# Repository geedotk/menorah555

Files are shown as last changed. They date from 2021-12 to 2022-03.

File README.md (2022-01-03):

# Menorah555

Menorah555 is an LED menorah that uses flickering LEDs to simulate the candles.
The shamash (helper candle) is removed and used to "light" the other candles.

## Circuit:
The menorah is built around LEDs that look like standard 5-mm LEDs (T-1 3/4), but
they actually have a chip inside that applies PWM to the LED to simulate a 
flickering flame. This means that no special driver circuitry is needed to create
that effect. Thus, the circuit has no microcontroller in it.

The shamash "candle" has a single flickering LED driven with a super cap. The shamash
board is a daughter board that can be unplugged, and the super cap will allow the
LED to keep lit for a while. A current limiter circuit keeps the inrush current down
so that charging the super cap does not cause the power supply to trip the current limit.

The "candle" lighting circuits are built around 555 timers. This could have been done
with fewer parts in a number of ways, but the 555 was selected to silence the
pundits that say, "it could have been done with a 555!" The 555 on each candle is used as
a set-reset flip-flop. Another 555 timer is configured to provide a power-on reset to
ensure that all LEDs (except for the shamash) are unlit when power is turned on. Triggering
of the 555 to turn on the LED is done with a reed switch. The shamash PCB has a magnet
mounted on it to trigger the reed switch and "light" the candle.

## PCB
Schematic capture and PCB layout were done in [KiCad](https://www.kicad.org/) 6.0.0.
There is no problem fitting everything on the PCB because the size is dictated more
by the aesthetics than the component size. In fact, the electrolytic capacitors selected
are MUCH larger than necessary because they are part of the suggestion of a candle shape.

## Base
The base of the menorah was designed in [FreeCAD](https://www.freecadweb.org/) 0.19 and
was designed to be made of acrylic or similar plastic and bent to the proper final
shape. It's not always easy to be consistent in heat-bending acrylic, so it may be better
to drill the mounting holes after bending. Otherwise, the base may not sit flat on a table.

## Flame Diffusors
The flame diffusors were designed in FreeCAD and were meant to be FDM printed in transparent
filament. The layer lines and in-fill will help to diffuse the light.

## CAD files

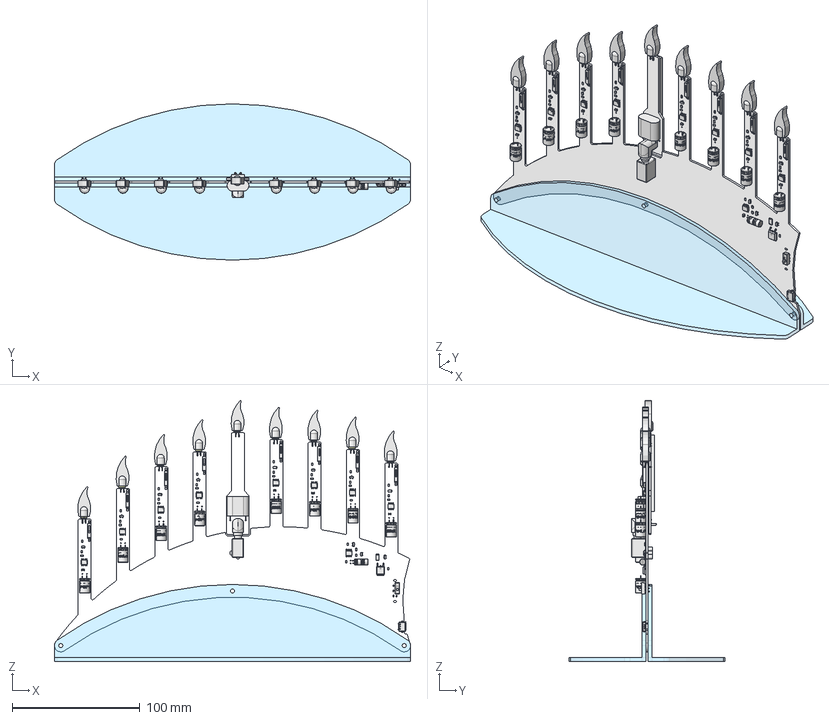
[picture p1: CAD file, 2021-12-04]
FreeCAD/menorah555_3d_model/menorah555_assembly.FCStd
278.6 x 122.2 x 204.3 mm
flame_diffuser001
base front
base rear
flame_diffusers_main

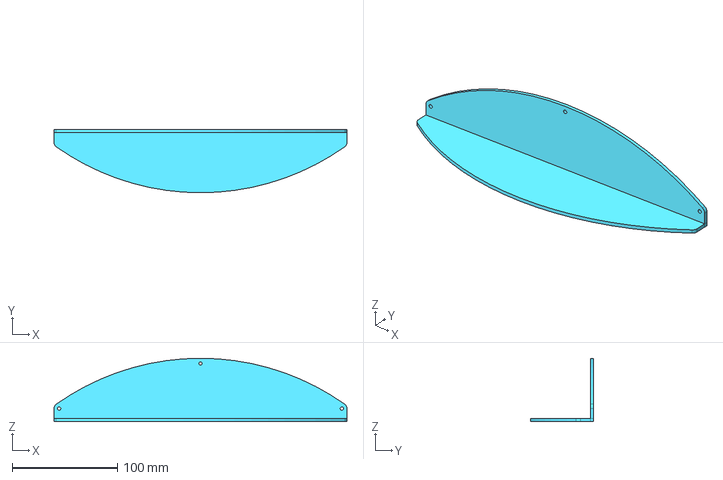
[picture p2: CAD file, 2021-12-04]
FreeCAD/base/menorah_base.step
278.6 x 60.3 x 60.3 mm

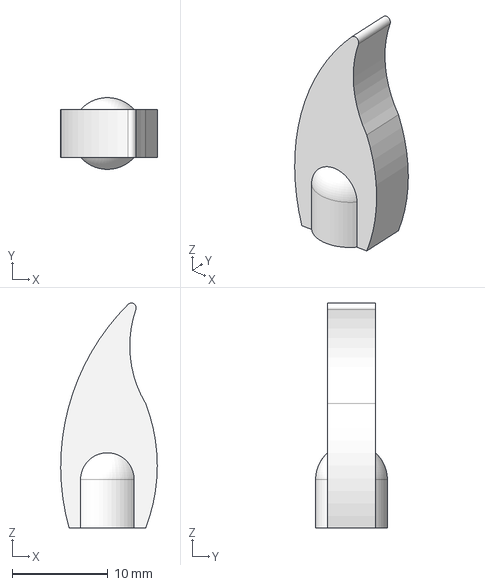
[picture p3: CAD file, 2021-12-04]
FreeCAD/flame_diffuser/flame_diffuser.step
10.1 x 7.50 x 23.5 mm

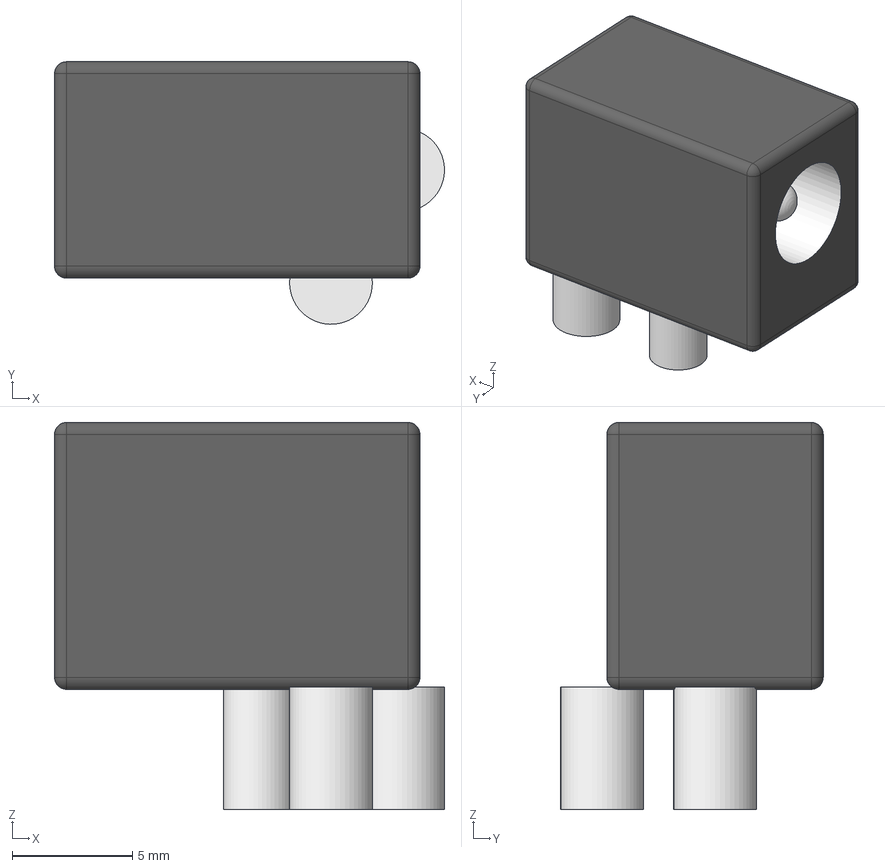
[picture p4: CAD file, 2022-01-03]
KiCad/menorah555_main/project_libraries/project_3dmodels/CON-SOCJ-2155.stp
16.2 x 10.9 x 16.1 mm

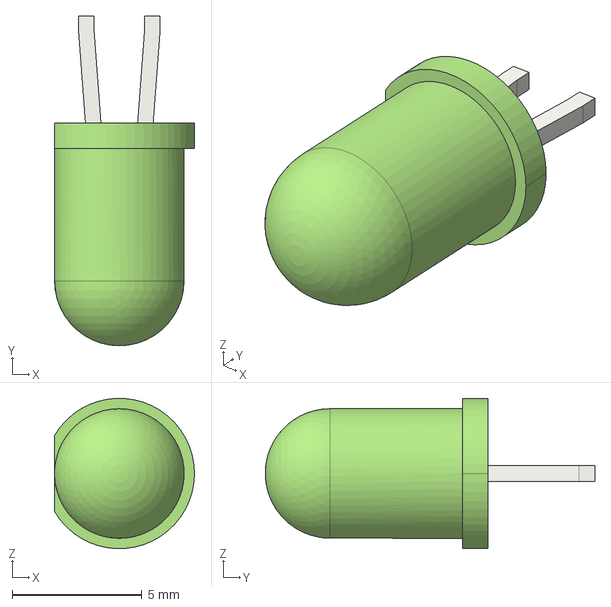
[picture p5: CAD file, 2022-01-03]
KiCad/menorah555_shamash/project_libraries/project_3dmodels/LED_D5.00mm_SMT_Horizontal_O3.81mm.step
5.40 x 12.7 x 5.79 mm

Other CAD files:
FreeCAD/base/menorah_base.FCStd
FreeCAD/flame_diffuser/flame_diffuser.FCStd
FreeCAD/flame_diffuser/flame_diffuser.stl

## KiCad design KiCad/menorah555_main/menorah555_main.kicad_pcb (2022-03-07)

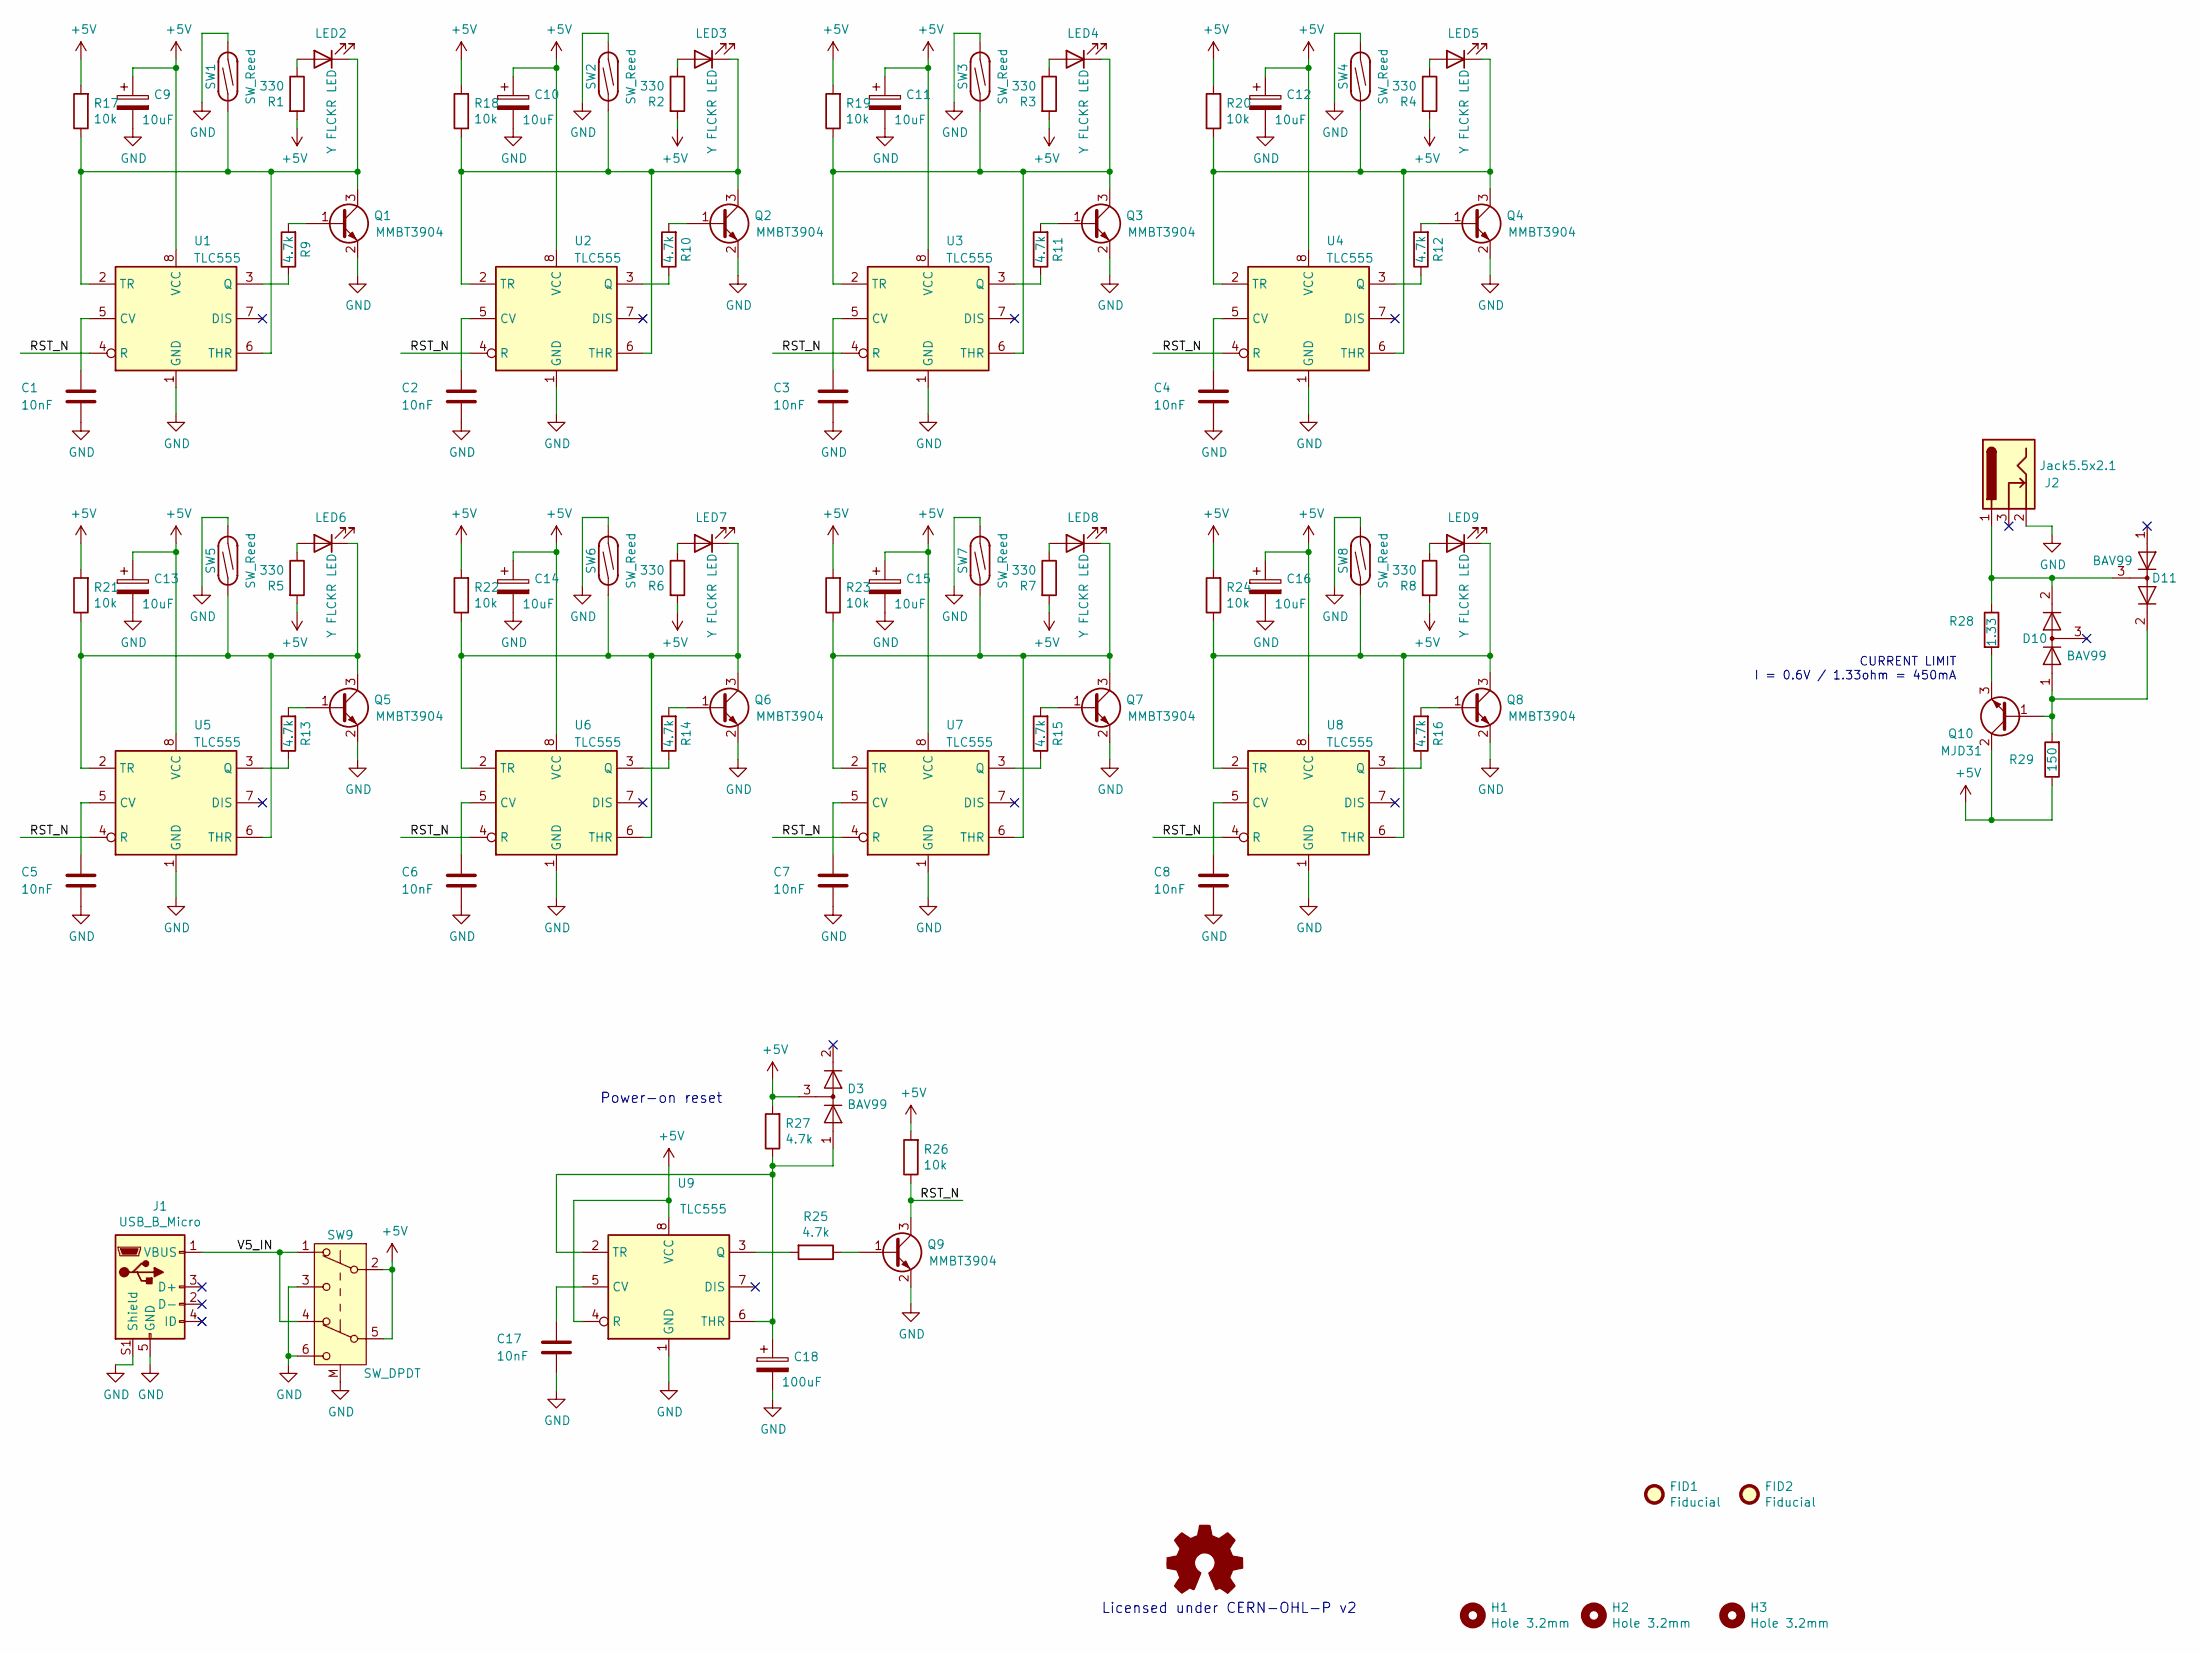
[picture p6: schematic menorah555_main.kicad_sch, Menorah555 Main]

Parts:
C1, C2, C3, C4, C5, C6, C7, C8, C17: 10nF; C_0805_2012Metric
C9, C10, C11, C12, C13, C14, C15, C16: 10uF; CP_Radial_Horizontal_D8.0mm_L12.0mm_P3.50mm
C18: 100uF; CP_Radial_Horizontal_D5.0mm_H11.0mm_P2.00mm
D3, D10, D11: BAV99; SOT-23
FID1, FID2: Fiducial; Fiducial_1mm_Mask2mm
H1, H2, H3: Hole 3.2mm; MountingHole_3.2mm_M3
J1: USB_B_Micro; AMPHENOL_10118194-0001LF
J2: Jack5.5x2.1; Gravitech_CONSOCJ2155_2.1mm_5.5mm_Barrel_Jack_Z2.35
LED2, LED3, LED4, LED5, LED6, LED7, LED8, LED9: Y FLCKR LED; LED_D5.0mm_Horizontal_SMT_O3.81mm
LOGO2: Logo_Open_Hardware_Small; OSHW-Logo2_9.8x8mm_SilkScreen
Q1, Q2, Q3, Q4, Q5, Q6, Q7, Q8, Q9: MMBT3904; SOT-23
Q10: MJD31; TO-252-2
R1, R2, R3, R4, R5, R6, R7, R8: 330; R_0805_2012Metric
R9, R10, R11, R12, R13, R14, R15, R16, R25, R27: 4.7k; R_0805_2012Metric
R17, R18, R19, R20, R21, R22, R23, R24, R26: 10k; R_0805_2012Metric
R28: 1.33; R_2010_5025Metric
R29: 150; R_0805_2012Metric
SW1, SW2, SW3, SW4, SW5, SW6, SW7, SW8: SW_Reed; SW_SPST_REED_59170-1-S-00-D
SW9: SW_DPDT; SW_Nidec_MFS201N-9-Z_DPDT_Straight
U1, U2, U3, U4, U5, U6, U7, U8, U9: TLC555; SOIC-8_3.9x4.9mm_P1.27mm

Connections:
+5V: C9.1, C10.1, C11.1, C12.1, C13.1, C14.1, C15.1, C16.1, D3.3 (K), Q10.2 (C), R1.2, R2.2, R3.2, R4.2, R5.2, R6.2, R7.2, R8.2, R17.2, R18.2, R19.2, R20.2, R21.2, R22.2, R23.2, R24.2, R26.2, R27.2, R29.1, SW9.2 (B), SW9.5 (B), U1.8 (VCC), U2.8 (VCC), U3.8 (VCC), U4.8 (VCC), U5.8 (VCC), U6.8 (VCC), U7.8 (VCC), U8.8 (VCC), U9.4 (R), U9.8 (VCC)
/RST_N: Q9.3 (C), R26.1, U1.4 (R), U2.4 (R), U3.4 (R), U4.4 (R), U5.4 (R), U6.4 (R), U7.4 (R), U8.4 (R)
/V5_IN: J1.1 (VBUS), SW9.1 (A), SW9.4 (A)
GND: C1.2, C2.2, C3.2, C4.2, C5.2, C6.2, C7.2, C8.2, C9.2, C10.2, C11.2, C12.2, C13.2, C14.2, C15.2, C16.2, C17.2, C18.2, J1.5 (GND), J1.S1 (Shield), J1.S2 (Shield), J1.S3 (Shield), J1.S4 (Shield), J1.S5 (Shield), J1.S6 (Shield), J2.2, Q1.2 (E), Q2.2 (E), Q3.2 (E), Q4.2 (E), Q5.2 (E), Q6.2 (E), Q7.2 (E), Q8.2 (E), Q9.2 (E), SW1.2, SW2.2, SW3.2, SW4.2, SW5.2, SW6.2, SW7.2, SW8.2, SW9.3 (C), SW9.6 (C), SW9.M, U1.1 (GND), U2.1 (GND), U3.1 (GND), U4.1 (GND), U5.1 (GND), U6.1 (GND), U7.1 (GND), U8.1 (GND), U9.1 (GND)
unnamed: C1.1, U1.5 (CV)
unnamed: C2.1, U2.5 (CV)
unnamed: C3.1, U3.5 (CV)
unnamed: C4.1, U4.5 (CV)
unnamed: C5.1, U5.5 (CV)
unnamed: C6.1, U6.5 (CV)
unnamed: C7.1, U7.5 (CV)
unnamed: C8.1, U8.5 (CV)
unnamed: C17.1, U9.5 (CV)
unnamed: C18.1, D3.1 (K), R27.1, U9.2 (TR), U9.6 (THR)
unnamed: D10.1 (K), D11.2 (A), Q10.1 (B), R29.2
unnamed: D10.2 (A), D11.3 (K), J2.1, R28.1
unnamed: LED2.1 (K), Q1.3 (C), R17.1, SW1.1, U1.2 (TR), U1.6 (THR)
unnamed: LED2.2 (A), R1.1
unnamed: LED3.1 (K), Q2.3 (C), R18.1, SW2.1, U2.2 (TR), U2.6 (THR)
unnamed: LED3.2 (A), R2.1
unnamed: LED4.1 (K), Q3.3 (C), R19.1, SW3.1, U3.2 (TR), U3.6 (THR)
unnamed: LED4.2 (A), R3.1
unnamed: LED5.1 (K), Q4.3 (C), R20.1, SW4.1, U4.2 (TR), U4.6 (THR)
unnamed: LED5.2 (A), R4.1
unnamed: LED6.1 (K), Q5.3 (C), R21.1, SW5.1, U5.2 (TR), U5.6 (THR)
unnamed: LED6.2 (A), R5.1
unnamed: LED7.1 (K), Q6.3 (C), R22.1, SW6.1, U6.2 (TR), U6.6 (THR)
unnamed: LED7.2 (A), R6.1
unnamed: LED8.1 (K), Q7.3 (C), R23.1, SW7.1, U7.2 (TR), U7.6 (THR)
unnamed: LED8.2 (A), R7.1
unnamed: LED9.1 (K), Q8.3 (C), R24.1, SW8.1, U8.2 (TR), U8.6 (THR)
unnamed: LED9.2 (A), R8.1
unnamed: Q1.1 (B), R9.2
unnamed: Q2.1 (B), R10.2
unnamed: Q3.1 (B), R11.2
unnamed: Q4.1 (B), R12.2
unnamed: Q5.1 (B), R13.2
unnamed: Q6.1 (B), R14.2
unnamed: Q7.1 (B), R15.2
unnamed: Q8.1 (B), R16.2
unnamed: Q9.1 (B), R25.1
unnamed: Q10.3 (E), R28.2
unnamed: R9.1, U1.3 (Q)
unnamed: R10.1, U2.3 (Q)
unnamed: R11.1, U3.3 (Q)
unnamed: R12.1, U4.3 (Q)
unnamed: R13.1, U5.3 (Q)
unnamed: R14.1, U6.3 (Q)
unnamed: R15.1, U7.3 (Q)
unnamed: R16.1, U8.3 (Q)
unnamed: R25.2, U9.3 (Q)

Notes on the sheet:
Power-on reset
CURRENT LIMIT I = 0.6V / 1.33ohm = 450mA
Licensed under CERN-OHL-P v2

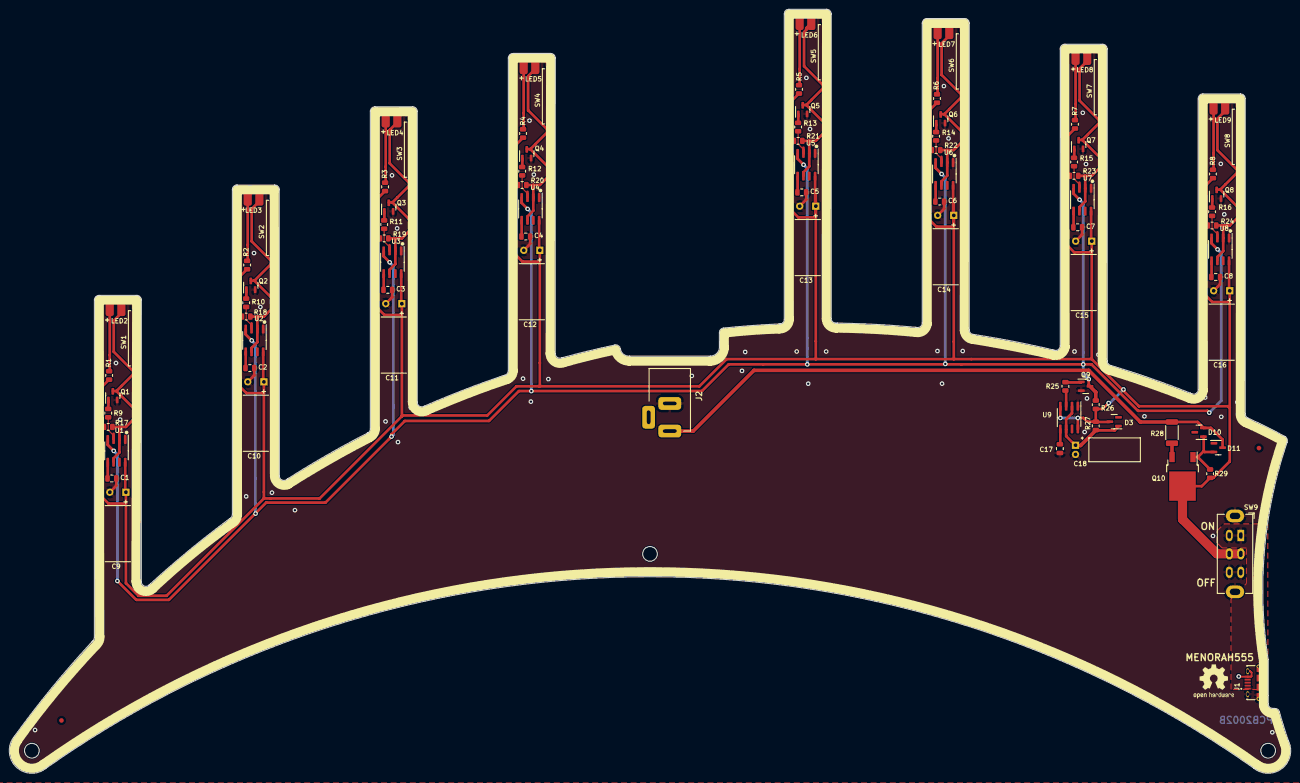
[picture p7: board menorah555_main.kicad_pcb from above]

Board: 2 copper layers, 278.6 x 166.1 mm, 94 parts (0 on the bottom side), 51 nets.

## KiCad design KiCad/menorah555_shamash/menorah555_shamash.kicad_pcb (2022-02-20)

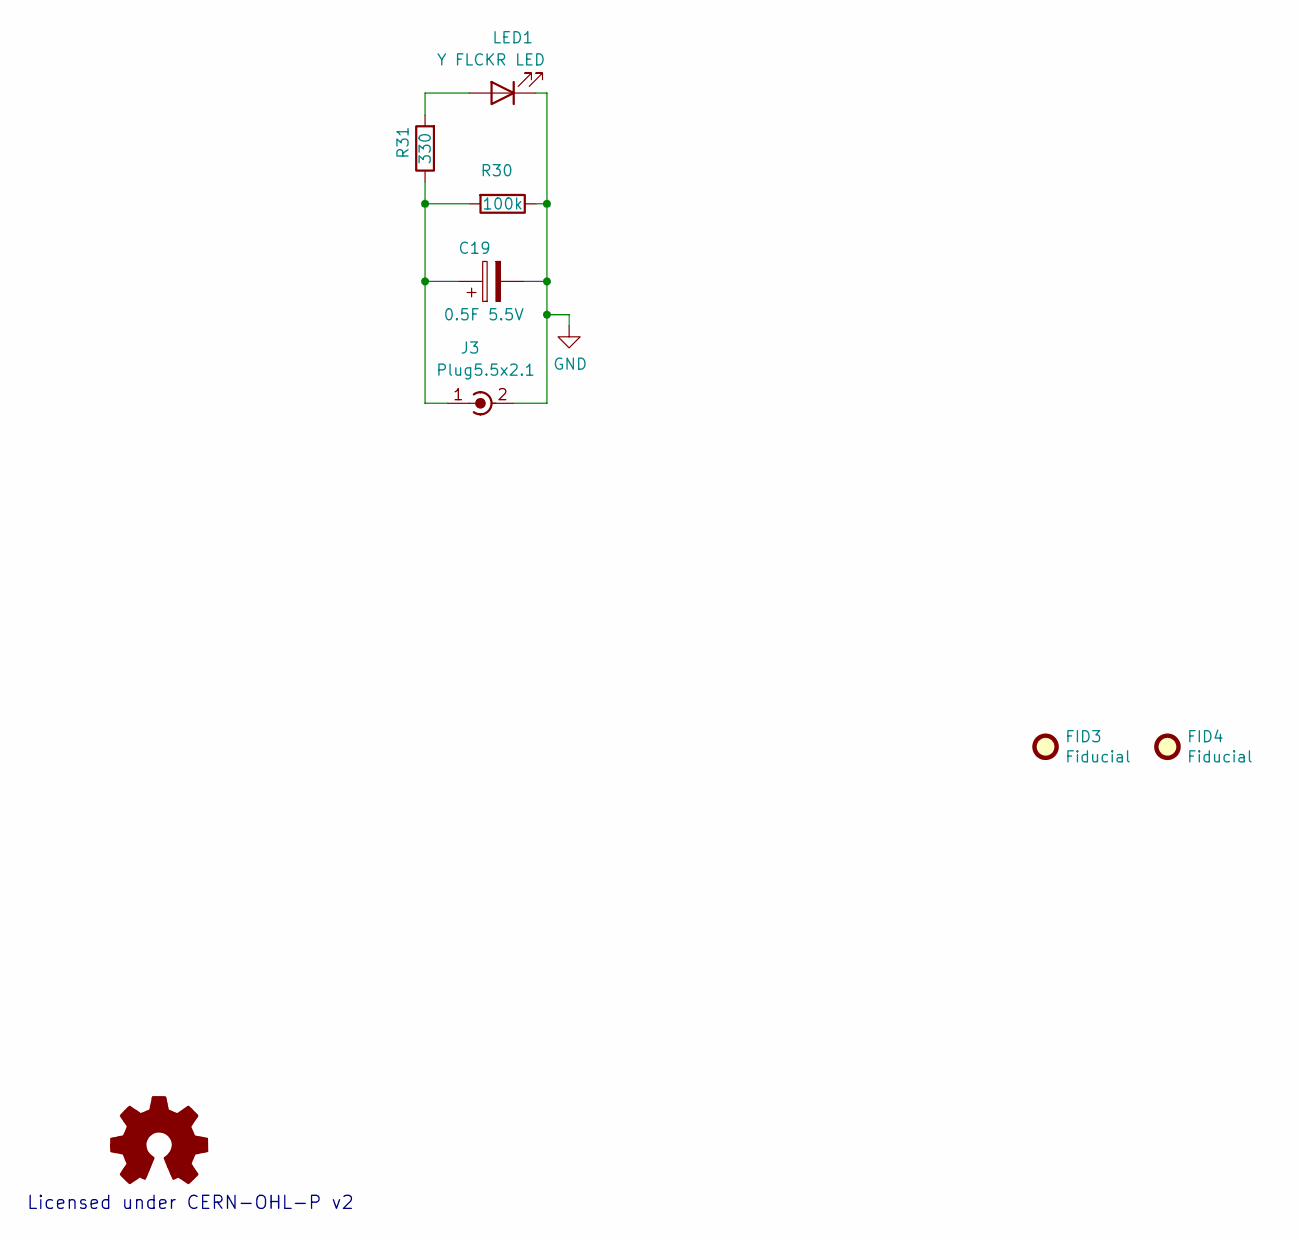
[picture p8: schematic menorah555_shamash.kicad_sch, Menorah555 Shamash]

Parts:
C19: 0.5F 5.5V; CP_Supercap_DGH504Q5R5_Horizontal
FID3, FID4: Fiducial; Fiducial_1mm_Mask2mm
J3: Plug5.5x2.1; KobiConn_173-5521TIP-EX_power_plug
LED1: Y FLCKR LED; LED_D5.0mm_Horizontal_SMT_O3.81mm
LOGO2: Logo_Open_Hardware_Small; OSHW-Logo2_9.8x8mm_SilkScreen
R30: 100k; R_0805_2012Metric
R31: 330; R_0805_2012Metric

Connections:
GND: C19.2, J3.2 (Ext), LED1.1 (K), R30.1
unnamed: C19.1, J3.1 (In), R30.2, R31.1
unnamed: LED1.2 (A), R31.2

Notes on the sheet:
Licensed under CERN-OHL-P v2

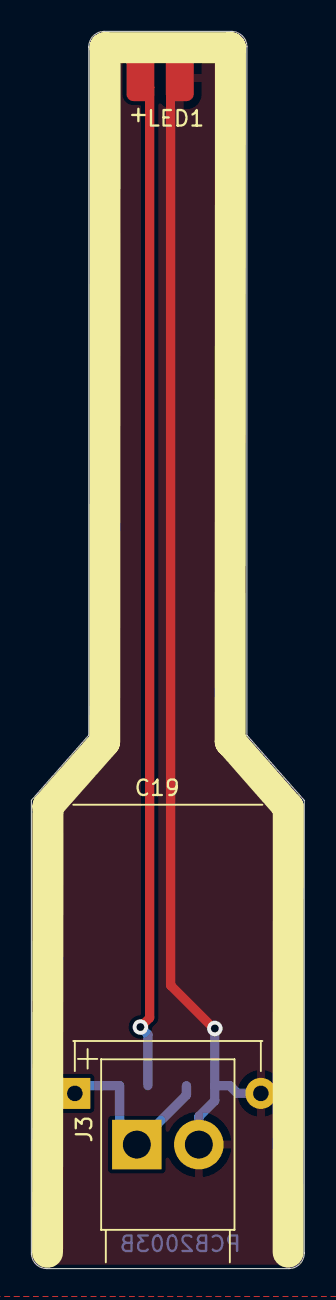
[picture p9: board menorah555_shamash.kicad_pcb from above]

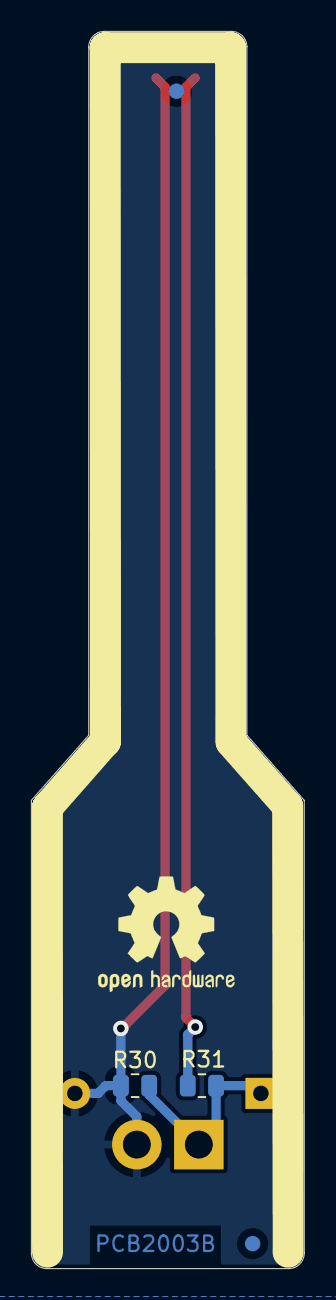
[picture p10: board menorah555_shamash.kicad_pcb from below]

Board: 2 copper layers, 17.6 x 79.8 mm, 8 parts (5 on the bottom side), 3 nets.

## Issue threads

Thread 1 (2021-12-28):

Shamash LED stays on a very long time after switch turned off

geedotk, 2021-12-28:
The shamash LED stays on for more than 20 minutes after the power switch is turned off. This is not really a serious issue, but I don't think this is what a user expects when turning off a power switch. On the first revision of the PCB (PCB2002A), I reworked the board to add a reversed diode across the D10 BAV99 diode. This allows current to flow the other direction when the power switch is turned off and allows the shamash LED to turn off almost immediately. Alternatively, something like a 1.8V zener diode (e.g. CMPZ4614) could be used to replace D10 (and change the current-sense resistor), but that seems to cost slightly more than two BAV99 diodes.
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

geedotk, 2022-01-03:
Added diode D11 to drain the supercap when the power switch is turned off. commit eef040ca97456bc392ca5020f1d7b778794f75fe

Closed 2022-01-03.

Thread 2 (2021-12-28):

USB connector is not hand-solderable

geedotk, 2021-12-28:
All of the parts on PCB2002A can be soldered by hand with the exception of the micro-USB connector (Molex 47590-0001), which must be reflowed. This can be replaced with something like the Amphenol 10118194-0001LF in case someone wants to hand solder the board.

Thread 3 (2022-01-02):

PCB must be broken into two parts when assembling

geedotk, 2022-01-02:
There are two PCBs in the rev A design: the main board and the shamash board. These were combined to reduce costs. However, when purchasing boards from JLCPCB, they charge extra for a second PCB in the design, so it would be better to make it two PCB designs. This way there won't be any need to break the PCBs apart and smooth the edges.

geedotk, 2022-01-03:
The combined PCB (PCB2002A) has been split into two boards: main (PCB2002B) and shamash (PCB2003B). commit bc6500bd1b43b3b79df0534fa05a82d8d8fb8849

Closed 2022-01-03.

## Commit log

2021-12-04 Initial version of the menorah555 project
    This contains the KiCad schematics and PCB files, as well as the FreeCAD models of
    the base and flame diffusers.
    [flame_diffuser.FCStd, flame_diffuser.step, flame_diffuser.stl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]
2021-12-30 Renamed directory
    The menorah PCB will be split into separate designs for the main board
    and for the shamash, so the directory is renamed as a step toward doing
    this
    [menorah555.kicad_pcb, menorah555.sch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]
2022-01-02 Updated design to KiCad 6.0.0
    Initially the design was created in KiCad 5.1.12. To update it to KiCad
    6.0.0 the path for the 3d models had to be changed from KISYS3DMOD to
    KICAD6_3DMODEL_DIR. Additionally, the .wrl file were all changed to
    .step files. No functional changes to the schematic or PCB were done
    when updating to KiCad 6
    [menorah555.kicad_pcb, menorah555.kicad_sch, menorah555.sch]
2022-01-03 Split PCB into separate main and shamash boards
    Previously, the main and shamash PCBs were combined into one file.
    Now they are separate PCBs so that they don't need to be cut apart and
    smoothed.
    [menorah555.kicad_pcb, menorah555_main.kicad_pcb, menorah555_main.kicad_sch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]
2022-01-03 Fixed long turn-off time
    Previously on the rev A PCB (PCB2002A), when power was turned off, the
    shamash would take a very long time (> 20 minutes) to fully turn off.
    Now a new diode, D11, has been added to drain the supercap when power is
    turned off with the switch.
    [menorah555_main.kicad_pcb, menorah555_main.kicad_sch]
2022-01-03 Made USB footprint hand-solderable
    The USB footprint was changed to be an Amphenol 10118194-0001LF so that
    it could be hand-soldered if desired.
    [menorah555_main.kicad_pcb, menorah555_main.kicad_sch]
2022-01-03 Eliminated silkscreen crossing edge cuts
    The DRC was giving warnings for silkscreen that overlapped with edge
    cuts because it was getting cut by the soldermask. The footprints for
    the LEDs and the shamash power connector were updated to delete the
    silkscreen outside of the board edge cuts
    [LED_D5.00mm_SMT_Horizontal_O3.81mm.step, menorah555_main.kicad_pcb, menorah555_main.kicad_sch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]
2022-01-03 Offset the J2 model in Z direction
    The 3d model for the J2 power jack has been offset by 2.35mm so that it
    will make the main PCB and shamash PCB line up.
    [CON-SOCJ-2155.stp, menorah555_main.kicad_pcb, menorah555_main.kicad_sch]
2022-01-04 Updated slide switch to ground the case
    The Nidec slide switch case had pins named 'M' that were not on the
    schematic, so they did not get connected on the PCB. Now those pins have
    been added to the symbol and connected to ground.
    [menorah555_main.kicad_pcb, menorah555_main.kicad_sch]
2022-02-20 Added silkscreen 2mm stripe at edge
    For aesthetic reasons, a 2mm silkscreen strip was added around the board
    on top and bottom. Gerbers were also generated
    [menorah555_main-B_Cu.gbr, menorah555_main-B_Fab.gbr, menorah555_main-B_Mask.gbr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]
2022-03-07 Removed unused layers
    There are no components on the bottom side, so there is no need for the
    bottom fab or bottom paste layers
    [menorah555_main.kicad_pcb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]
2022-03-07 Added alignment holes to paste layer
    In order to facilitate hand stenciling solder paste onto the board,
    holes have been added to the front paste layer that align with two
    mounting holes.
    [menorah555_main-B_Cu.gbr, menorah555_main-B_Mask.gbr, menorah555_main-B_Silkscreen.gbr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]
